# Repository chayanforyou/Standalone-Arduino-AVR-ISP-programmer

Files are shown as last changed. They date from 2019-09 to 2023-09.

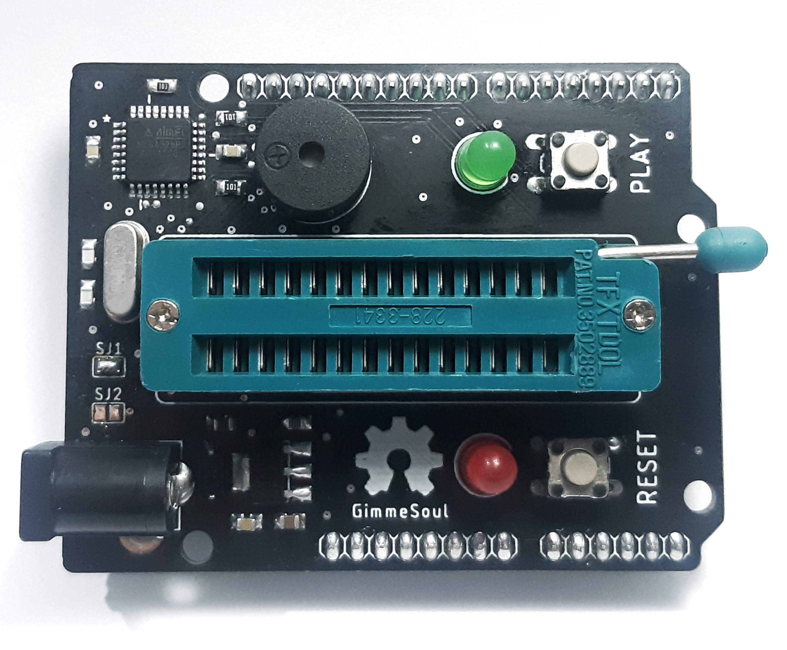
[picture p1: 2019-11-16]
Others/Mounted PCB.jpg

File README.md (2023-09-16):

# Standalone AVR programmer (GimmeSoul)




GimmeSoul is a standalone (no computer needed) bootloader programmer for ATmega328P. It can be used to facilitate programming of chips used by [Arduino UNO](https://store.arduino.cc/usa/arduino-uno-rev3) and [Senaino](https://github.com/import-tiago/Senaino), for example. 

This makes the process of flash the ICs so much faster than conventional way and eliminates the need for a computer.

## Mounted PCB


## PCB Gerber Preview


## Schematic


## Bill of Materials
To mount the components on the board, follow the instructions: [Designator References](https://github.com/import-tiago/GimmeSoul/blob/master/Hardware/1.%20Mounting/Silk%20Screen.png)

| Qty | Parts | Description | Value | Package |
|--|--|--|--|--|
2|R2/R3|SMD Resistor|100R ±5%|R0805
1|R1|SMD Resistor|10k ±5%|R0805
4|C1/C2/C4/C6|SMD Capacitor|100 nF / 50V|C0805
2|C3/C5|SMD Capacitor|1 uF / 50V|C0805
2|C7/C8|SMD Capacitor|22 pF / 50V|C0805
1|D2|SMD Diode|1N4007|SOD123
1|U1|SMD Microcontroller|ATmega328P|TQFP-32
1|U2|SMD Voltage Regulator|LM1117MP-5.0|SOT223
2|S1/S2|PTH Tact Switch|DPST|6 x 6 mm
1|Q1|PTH Crystal|16 MHz|HC49/S
1|SG5|PTH Buzzer|5V Passive|F/QMBIII
1|LED1|PTH LED|Green|5 mm
1|LED2|PTH LED|Red|5 mm
2|JP1/JP4|PTH Pin Header|Male 180°|1X08
1|JP2|PTH Pin Header|Male 180°|1X10
1|JP3|PTH Pin Header|Male 180°|1X06
1|ZX1|PTH ZIF socket|28-pin|Slim Width

## How To
[SETUP Tutorial](https://github.com/import-tiago/GimmeSoul/wiki/SETUP)

## Video
[# GimmeSoul - Demo](https://vimeo.com/363052289?activityReferer=1)

### Contributing
0. Give this project a :star:
1. Create an issue and describe your idea.
2. [Fork it](https://github.com/import-tiago/GimmeSoul/fork).
3. Create your feature branch (`git checkout -b my-new-feature`).
4. Commit your changes (`git commit -a -m "Added feature title"`).
5. Publish the branch (`git push origin my-new-feature`).
6. Create a new pull request.
7. Done! :heavy_check_mark:

### License Information
<br /><span xmlns:dct="http://purl.org/dc/terms/" property="dct:title">GimmeSoul</span> by <a xmlns:cc="http://creativecommons.org/ns#" href="https://github.com/import-tiago" property="cc:attributionName" rel="cc:attributionURL">Tiago Silva</a> is licensed under a <a rel="license" href="http://creativecommons.org/licenses/by-sa/4.0/">Creative Commons Attribution-ShareAlike 4.0 International License</a>.<br />Based on a work at <a xmlns:dct="http://purl.org/dc/terms/" href="[Standalone AVR Chip Programmer](https://learn.adafruit.com/standalone-avr-chip-programmer/)" rel="dct:source">[Standalone AVR Chip Programmer](https://learn.adafruit.com/standalone-avr-chip-programmer/)</a>.<br />Permissions beyond the scope of this license may be available at <a xmlns:cc="http://creativecommons.org/ns#" href="https://twitter.com/import_tiago" rel="cc:morePermissions">tiagodepaulasilva@gmail.com</a>.

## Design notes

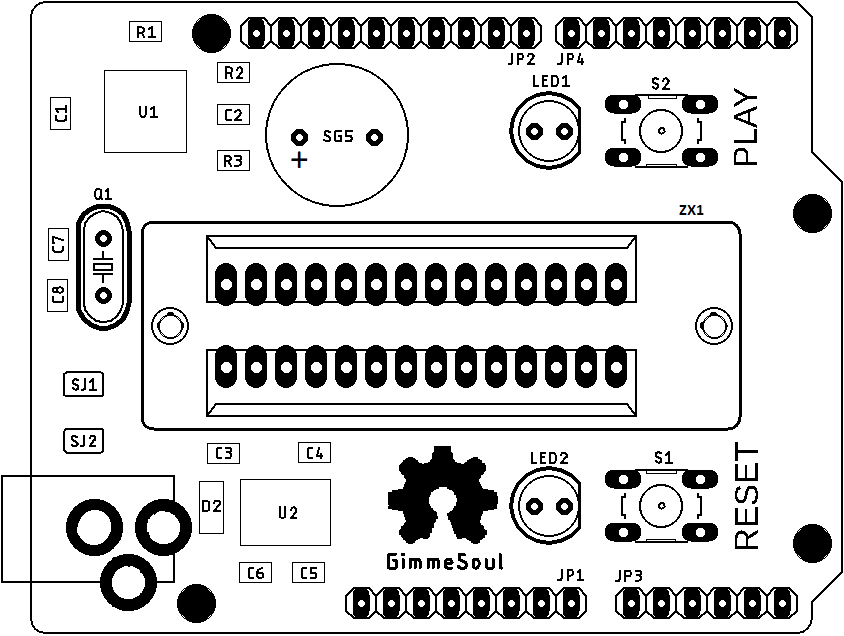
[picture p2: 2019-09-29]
Hardware/1. Mounting/Silk Screen.png

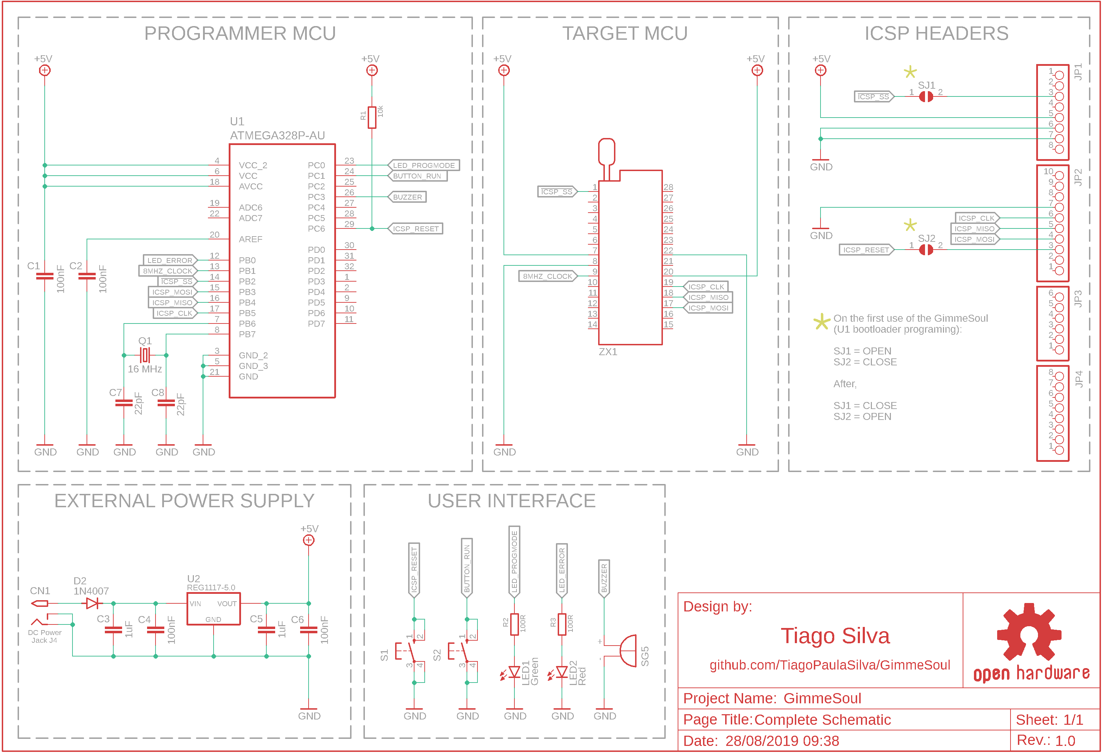
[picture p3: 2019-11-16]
Others/GimmeSoul Schematic Preview.png

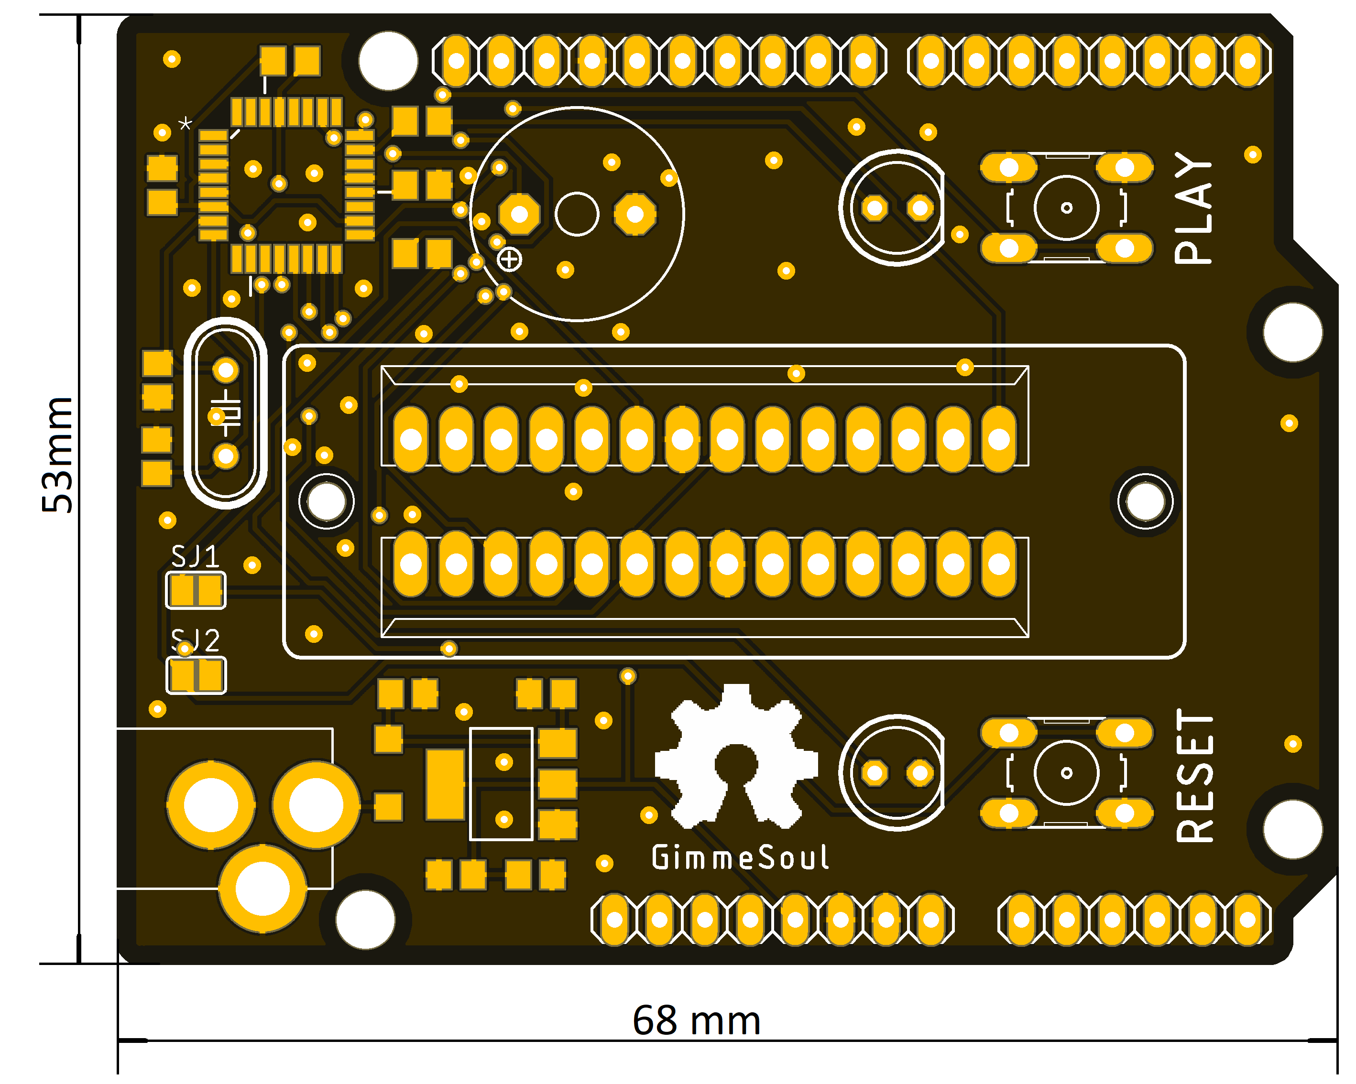
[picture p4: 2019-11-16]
Others/GimmeSoul Gerber Preview.png

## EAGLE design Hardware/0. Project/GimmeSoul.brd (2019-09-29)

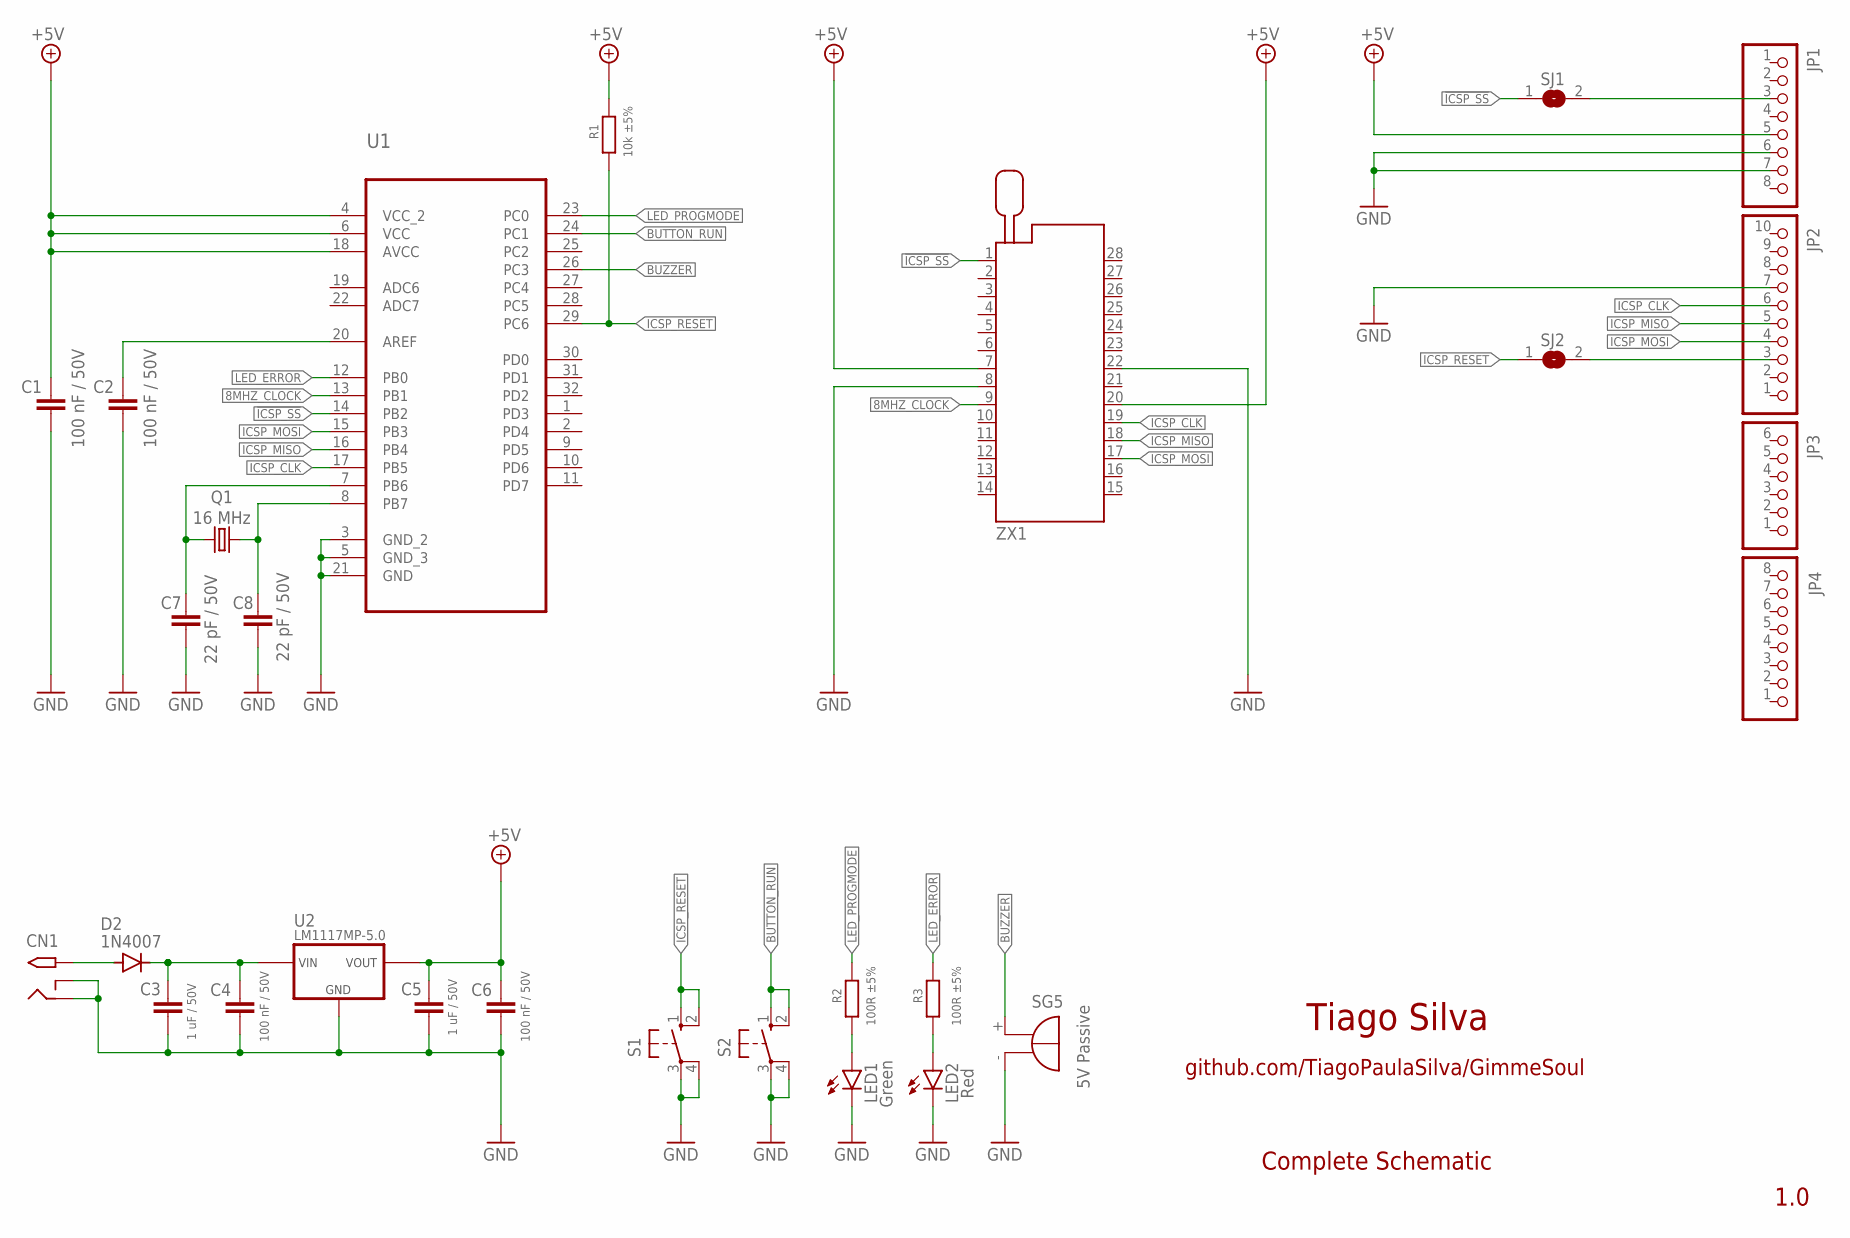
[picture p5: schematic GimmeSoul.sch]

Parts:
C1, C2, C4, C6: 100 nF / 50V; C0805
C3, C5: 1 uF / 50V; C0805
C7, C8: 22 pF / 50V; C0805
CN1: 2.1MMJACKTHM; PJ-102A
D2: 1N4007; SOD123
JP1, JP4: PINHD-1X8; 1X08
JP2: PINHD-1X10_ARD; 1X10
JP3: PINHD-1X6; 1X06
LED1: Green; LED5MM
LED2: Red; LED5MM
Q1: 16 MHz; HC49/S
R1: 10k ±5%; R0805
R2, R3: 100R ±5%; R0805
S1, S2: 10-XX; B3F-10XX
SG5: 5V Passive; F/QMBIII
SJ1, SJ2: SJ
U1: ATMEGA328P-AU; QFP80P900X900X120-32N
U2: LM1117MP-5.0; SOT223
ZX1: 228-4817-00-0602J

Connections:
8MHZ_CLOCK: U1.13 (PB1), ZX1.9
!ICSP_SS: SJ1.1, U1.14 (PB2), ZX1.1
+5V: C1.2, C5.1, C6.1, JP1.5, R1.1, U1.4 (VCC_2), U1.6 (VCC), U1.18 (AVCC), U2.2 (VOUT), U2.4 (VOUT), ZX1.7, ZX1.20
BUTTON_RUN: S2.1 (S), S2.2 (S1), U1.24 (PC1)
BUZZER: SG5.+ (-), U1.26 (PC3)
GND: C1.1, C2.1, C3.2, C4.2, C5.2, C6.2, C7.1, C8.1, CN1.RING, CN1.RING_SW, JP1.6, JP1.7, JP2.7, LED1.K (C), LED2.K (C), S1.3, S1.4 (P1), S2.3, S2.4 (P1), SG5.- (+), U1.3 (GND_2), U1.5 (GND_3), U1.21 (GND), U2.1 (GND), ZX1.8, ZX1.22
ICSP_CLK: JP2.6, U1.17 (PB5), ZX1.19
ICSP_MISO: JP2.5, U1.16 (PB4), ZX1.18
ICSP_MOSI: JP2.4, U1.15 (PB3), ZX1.17
ICSP_RESET: R1.2, S1.1 (S), S1.2 (S1), SJ2.1, U1.29 (PC6)
LED_ERROR: R3.1, U1.12 (PB0)
LED_PROGMODE: R2.1, U1.23 (PC0)
unnamed: LED1.A, R2.2
unnamed: CN1.TIP, D2.A
unnamed: LED2.A, R3.2
unnamed: C3.1, C4.1, D2.C, U2.3 (VIN)
unnamed: JP2.3, SJ2.2
unnamed: JP1.3, SJ1.2
unnamed: C7.2, Q1.1, U1.7 (PB6)
unnamed: C8.2, Q1.2, U1.8 (PB7)
unnamed: C2.2, U1.20 (AREF)

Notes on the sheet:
Tiago Silva
github.com/TiagoPaulaSilva/GimmeSoul
1.0
Complete Schematic

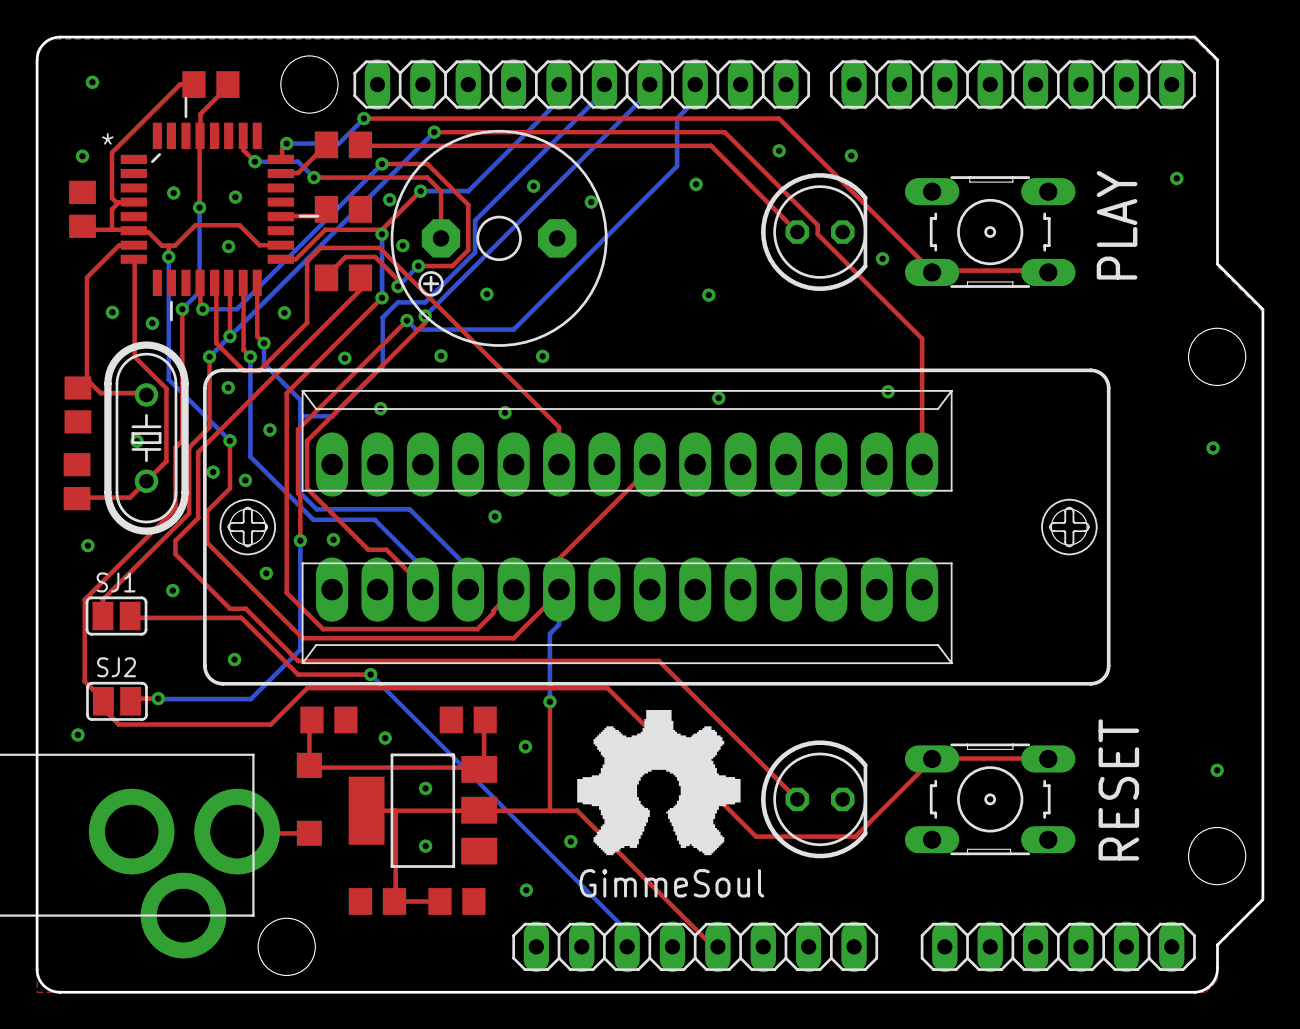
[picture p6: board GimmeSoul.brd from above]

Board: 2 copper layers, 68.6 x 53.5 mm, 28 parts (0 on the bottom side), 21 nets.

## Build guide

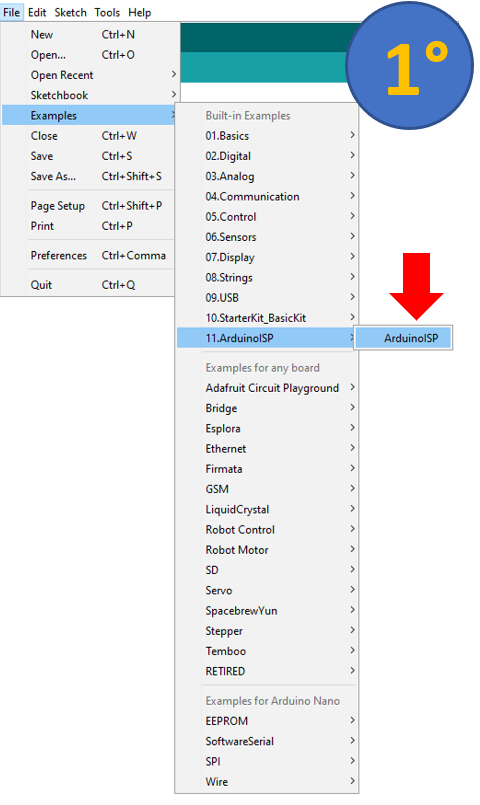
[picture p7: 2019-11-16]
Others/Tutorial/Step (2).png

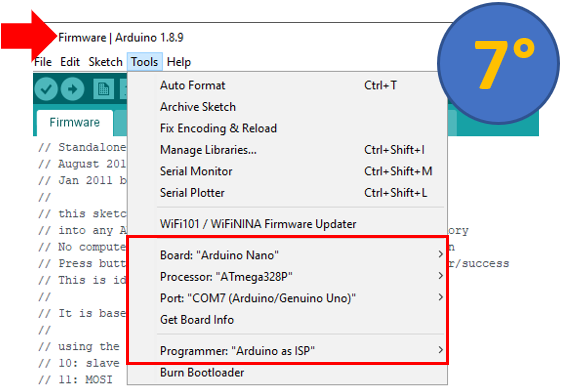
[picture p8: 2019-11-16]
Others/Tutorial/Step (10).png

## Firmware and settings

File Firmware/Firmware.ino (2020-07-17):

// Standalone AVR ISP programmer
// August 2011 by Limor Fried / Ladyada / Adafruit
// Jan 2011 by Bill Westfield ("WestfW")
//
// this sketch allows an Arduino to program a flash program
// into any AVR if you can fit the HEX file into program memory
// No computer is necessary. Two LEDs for status notification
// Press button to program a new chip. Piezo beeper for error/success 
// This is ideal for very fast mass-programming of chips!
//
// It is based on AVRISP
//
// using the following pins:
// 10: slave reset
// 11: MOSI
// 12: MISO
// 13: SCK
//  9: 8 MHz clock output - connect this to the XTAL1 pin of the AVR
//     if you want to program a chip that requires a crystal without
//     soldering a crystal in
// ----------------------------------------------------------------------


#include "optiLoader.h"
#include "SPI.h"

// Global Variables
int pmode=0;
byte pageBuffer[128];		       /* One page of flash */


/*
 * Pins to target
 */
#define SCK 13
#define MISO 12
#define MOSI 11
#define RESET 10
#define CLOCK 9     // self-generate 8mhz clock - handy!

#define BUTTON A1
#define PIEZOPIN A3

// Set to 1 to enable autostart. This automatically starts programming
// when a chip is inserted. How this detection happens is determined by
// the DETECT_* constants below. This is disabled by default, since the
// default settings require adding a pulldown (see below).
#define AUTOSTART 0

// Pin to use for detecting chip presence. This defaults to the
// (target) RESET pin, which detects the (internal) reset pullup on the
// target chip or board. For this to work, there should be a pulldown on
// the programmer side (which is big enough to not interfere with the
// target pullup). Alternatively, for self-powered boards, this could be
// set to an I/O pin that is connected to the targets VCC (still
// requires a pulldown on the programmer side).
#define DETECT RESET

// The DETECT pin level that indicates a chip is present.
#define DETECT_ACTIVE HIGH

// Debounce delay: The DETECT pin must be stable for this long before it
// is seen as changed. This applies both after removing and after
// re-inserting the chip.
#define DETECT_DEBOUNCE_MS 500

void setup () {
  Serial.begin(57600);			/* Initialize serial for status msgs */
  Serial.println("\nAdaBootLoader Bootstrap programmer (originally OptiLoader Bill Westfield (WestfW))");

  pinMode(PIEZOPIN, OUTPUT);

  pinMode(LED_PROGMODE, OUTPUT);
  pulse(LED_PROGMODE,2);
  pinMode(LED_ERR, OUTPUT);
  pulse(LED_ERR, 2);

  pinMode(BUTTON, INPUT);     // button for next programming
  digitalWrite(BUTTON, HIGH); // pullup
  
  pinMode(CLOCK, OUTPUT);
  // setup high freq PWM on pin 9 (timer 1)
  // 50% duty cycle -> 8 MHz
  OCR1A = 0;
  ICR1 = 1;
  // OC1A output, fast PWM
  TCCR1A = _BV(WGM11) | _BV(COM1A1);
  TCCR1B = _BV(WGM13) | _BV(WGM12) | _BV(CS10); // no clock prescale



  
}

#if AUTOSTART != 0
bool detect_chip() {
  // The most recently read detection state (true is chip present, false is no
  // chip present). Default is to assume a chip is present, to prevent
  // autostarting on powerup, only after *inserting* a chip.
  static bool detected = true;
  // The most recent detection state that has been stable.
  static bool debounced = detected;
  // The timestamp of the most recent change, or 0 when the pin is
  // stable.
  static unsigned long last_change = 0;

  // See if the pin changed
  unsigned long now = millis();
  bool prev_detected = detected;
  detected = (digitalRead(DETECT) == DETECT_ACTIVE);

  if (detected != prev_detected)
    last_change = now;

  if (detected != debounced && (now - last_change) > DETECT_DEBOUNCE_MS) {
    // If stable for long enough, update the debounced state and clear
    // the last_change value. Keep the previous value, to detect changes
    last_change = 0;
    debounced = detected;

    // Detect when a chip is inserted
    if (debounced)
      return true;
  }

  // No change, or chip removed
  return false;
}
#endif

void loop (void) {
  #if AUTOSTART != 0
  Serial.println("\nInsert next chip to autostart or type 'G' or hit BUTTON to force start");
  #else
  Serial.println("\nType 'G' or hit BUTTON for next chip");
  #endif
  while (1) {
    #if AUTOSTART != 0
    if (detect_chip()) {
      Serial.println("Chip detected, autostarting..");
      break;
    }
    #endif
    if  ((! digitalRead(BUTTON)) || (Serial.read() == 'G'))
      break;  
  }
    
  target_poweron();			/* Turn on target power */

  uint16_t signature;
  image_t *targetimage;
        
  if (! (signature = readSignature()))		// Figure out what kind of CPU
    error("Signature fail");
  if (! (targetimage = findImage(signature)))	// look for an image
    error("Image fail");

  Serial.println();
  Serial.println("Erasing chip");
  eraseChip();
  
  if (! programFuses(targetimage->image_progfuses))	// get fuses ready to program
    error("Programming Fuses fail");
  
  if (! verifyFuses(targetimage->image_progfuses, targetimage->fusemask) ) {
    error("Failed to verify fuses");
  } 

  Serial.println("Fuses set & verified");
  end_pmode();
  start_pmode();

  byte *hextext = targetimage->image_hexcode;  
  uint16_t pageaddr = 0;
  uint8_t pagesize = pgm_read_byte(&targetimage->image_pagesize);
  Serial.print("Page size: "); Serial.println(pagesize, DEC);
  uint16_t chipsize = pgm_read_word(&targetimage->chipsize);
  Serial.print("Chip size: "); Serial.println(chipsize, DEC);
  
  while (pageaddr < chipsize && hextext) {
     Serial.print("Writing address $"); Serial.println(pageaddr, HEX);
     byte *hextextpos = readImagePage (hextext, pageaddr, pagesize, pageBuffer);
          
     boolean blankpage = true;
     for (uint8_t i=0; i<pagesize; i++) {
       if (pageBuffer[i] != 0xFF) blankpage = false;
     }          
     if (! blankpage) {
       if (! flashPage(pageBuffer, pageaddr, pagesize))	
	       error("Flash programming failed");
     }
     hextext = hextextpos;
     pageaddr += pagesize;
  }
  
  // Set fuses to 'final' state
  if (! programFuses(targetimage->image_normfuses))
    error("Programming Fuses fail");

  delay(100);
  end_pmode();
  delay(100);
  start_pmode();
  delay(100);
  
  Serial.println("\nVerifing flash...");
  if (! verifyImage(targetimage->image_hexcode) ) {
    error("Failed to verify chip");
  } else {
    Serial.println("\tFlash verified correctly!");
  }

  if (! verifyFuses(targetimage->image_normfuses, targetimage->fusemask) ) {
    error("Failed to verify fuses");
  } else {
    Serial.println("Fuses verified correctly!");
  }
  target_poweroff();			/* turn power off */
  programmingSucess();
}

void programmingSucess(){
  tone(PIEZOPIN, 523, 100);
  delay(400);
  tone(PIEZOPIN, 523, 200);
  delay(200);
  tone(PIEZOPIN, 698, 800);
  delay(500);
  digitalWrite(LED_PROGMODE, LOW);
}

void programmingError(){
    digitalWrite(LED_ERR, HIGH);
    digitalWrite(LED_PROGMODE, LOW);
    tone(PIEZOPIN, 622, 500);
    delay(500);
    digitalWrite(LED_ERR, LOW);
    digitalWrite(LED_PROGMODE, HIGH);
    tone(PIEZOPIN, 460, 500);
    delay(500);
}

void error(const char *string) {
  Serial.println(string); 
  digitalWrite(LED_ERR, HIGH);  

  
  while(digitalRead(BUTTON)) {
    programmingError();
  }
  
}

void start_pmode () {
  pinMode(13, INPUT); // restore to default

  SPI.begin();
  SPI.setClockDivider(SPI_CLOCK_DIV128); 
  
  debug("...spi_init done");
  // following delays may not work on all targets...
  pinMode(RESET, OUTPUT);
  digitalWrite(RESET, HIGH);
  pinMode(SCK, OUTPUT);
  digitalWrite(SCK, LOW);
  delay(50);
  digitalWrite(RESET, LOW);
  delay(50);
  pinMode(MISO, INPUT);
  pinMode(MOSI, OUTPUT);
  debug("...spi_transaction");
  spi_transaction(0xAC, 0x53, 0x00, 0x00);
  debug("...Done");
  pmode = 1;
}

void end_pmode () {
  SPI.end();
  digitalWrite(MISO, LOW);		/* Make sure pullups are off too */
  pinMode(MISO, INPUT);
  digitalWrite(MOSI, LOW);
  pinMode(MOSI, INPUT);
  digitalWrite(SCK, LOW);
  pinMode(SCK, INPUT);
  digitalWrite(RESET, LOW);
  pinMode(RESET, INPUT);
  pmode = 0;
}


/*
 * target_poweron
 * begin programming
 */
boolean target_poweron (){
  pinMode(LED_PROGMODE, OUTPUT);
  digitalWrite(LED_PROGMODE, HIGH);
  digitalWrite(RESET, LOW);  // reset it right away.
  pinMode(RESET, OUTPUT);
  delay(100);
  Serial.print("Starting Program Mode");
  start_pmode();
  Serial.println(" [OK]");
  return true;
}

boolean target_poweroff (){
  end_pmode();
  
  return true;
}

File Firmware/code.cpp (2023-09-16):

#include "optiLoader.h"

/*
 * Bootload images.
 * These are the intel Hex files produced by the optiboot makefile,
 * with a small amount of automatic editing to turn them into C strings,
 * and a header attched to identify them
 */

extern image_t *images[];
extern uint8_t NUMIMAGES;

SPISettings fuses_spisettings = SPISettings(100000, MSBFIRST, SPI_MODE0);
SPISettings flash_spisettings = SPISettings(1000000, MSBFIRST, SPI_MODE0);

/*
 * readSignature
 * read the bottom two signature bytes (if possible) and return them
 * Note that the highest signature byte is the same over all AVRs so we skip it
 */

uint16_t readSignature (void)
{
    
  uint16_t target_type = 0;
  Serial.print("\nReading signature:");
  
  SPI.beginTransaction(fuses_spisettings); 
  
  target_type = spi_transaction(0x30, 0x00, 0x01, 0x00);
  target_type <<= 8;
  target_type |= spi_transaction(0x30, 0x00, 0x02, 0x00);

  SPI.endTransaction();
  
  Serial.println(target_type, HEX);
  if (target_type == 0 || target_type == 0xFFFF) {
    if (target_type == 0) {
      Serial.println("  (no target attached?)");
    }
  }
  return target_type;
}

/*
 * findImage
 *
 * given 'signature' loaded with the relevant part of the device signature,
 * search the hex images that we have programmed in flash, looking for one
 * that matches.
 */
image_t *findImage (uint16_t signature)
{
  image_t *ip;
  Serial.println("Searching for image...");

  for (byte i=0; i < NUMIMAGES; i++) {
    ip = images[i];

    if (ip && (pgm_read_word(&ip->image_chipsig) == signature)) {
	Serial.print("  Found \"");
	flashprint(&ip->image_name[0]);
	Serial.print("\" for ");
	flashprint(&ip->image_chipname[0]);
	Serial.println();

	return ip;
    }
  }
  Serial.println(" Not Found");
  return 0;
}

/*
 * programmingFuses
 * Program the fuse/lock bits
 */
boolean programFuses (const byte *fuses)
{
    
  byte f;
  Serial.print("\nSetting fuses");

  busyWait();
  f = pgm_read_byte(&fuses[FUSE_PROT]);
  if (f) {
    Serial.print("\n  Set Lock Fuse to: ");
    Serial.print(f, HEX);
    Serial.print(" -> ");
    SPI.beginTransaction(fuses_spisettings);
    Serial.print(spi_transaction(0xAC, 0xE0, 0x00, f), HEX);
    SPI.endTransaction();
  }
  busyWait();
  f = pgm_read_byte(&fuses[FUSE_LOW]);
  if (f) {
    Serial.print("  Set Low Fuse to: ");
    Serial.print(f, HEX);
    Serial.print(" -> ");
    SPI.beginTransaction(fuses_spisettings);
    Serial.print(spi_transaction(0xAC, 0xA0, 0x00, f), HEX);
    SPI.endTransaction();
  }
  busyWait();
  f = pgm_read_byte(&fuses[FUSE_HIGH]);
  if (f) {
    Serial.print("  Set High Fuse to: ");
    Serial.print(f, HEX);
    Serial.print(" -> ");
    SPI.beginTransaction(fuses_spisettings);
    Serial.print(spi_transaction(0xAC, 0xA8, 0x00, f), HEX);
    SPI.endTransaction();
  }
  busyWait();
  f = pgm_read_byte(&fuses[FUSE_EXT]);
  if (f) {
    Serial.print("  Set Ext Fuse to: ");
    Serial.print(f, HEX);
    Serial.print(" -> ");
    SPI.beginTransaction(fuses_spisettings);
    Serial.print(spi_transaction(0xAC, 0xA4, 0x00, f), HEX);
    SPI.endTransaction();
  }
  Serial.println();
    
  return true;			/* */
}

/*
 * verifyFuses
 * Verifies a fuse set
 */
boolean verifyFuses (const byte *fuses, const byte *fusemask)
{
  byte f;

  Serial.println("Verifying fuses...");
  f = pgm_read_byte(&fuses[FUSE_PROT]);
  if (f) {
    SPI.beginTransaction(fuses_spisettings);
    uint8_t readfuse = spi_transaction(0x58, 0x00, 0x00, 0x00);  // lock fuse
    SPI.endTransaction();

    readfuse &= pgm_read_byte(&fusemask[FUSE_PROT]);
    Serial.print("\tLock Fuse: "); Serial.print(f, HEX);  Serial.print(" is "); Serial.print(readfuse, HEX);
    if (readfuse != f) 
      return false;
  }
  f = pgm_read_byte(&fuses[FUSE_LOW]);
  if (f) {
    SPI.beginTransaction(fuses_spisettings);
    uint8_t readfuse = spi_transaction(0x50, 0x00, 0x00, 0x00);  // low fuse
    SPI.endTransaction();
        
    Serial.print("\tLow Fuse: 0x");  Serial.print(f, HEX); Serial.print(" is 0x"); Serial.print(readfuse, HEX);
    readfuse &= pgm_read_byte(&fusemask[FUSE_LOW]);
    if (readfuse != f) 
      return false;
  }
  f = pgm_read_byte(&fuses[FUSE_HIGH]);
  if (f) {
    SPI.beginTransaction(fuses_spisettings);
    uint8_t readfuse = spi_transaction(0x58, 0x08, 0x00, 0x00);  // high fuse
    SPI.endTransaction();
        
    readfuse &= pgm_read_byte(&fusemask[FUSE_HIGH]);
    Serial.print("\tHigh Fuse: 0x");  Serial.print(f, HEX); Serial.print(" is 0x");  Serial.print(readfuse, HEX);
    if (readfuse != f) 
      return false;
  }
  f = pgm_read_byte(&fuses[FUSE_EXT]);
  if (f) {
    SPI.beginTransaction(fuses_spisettings);
    uint8_t readfuse = spi_transaction(0x50, 0x08, 0x00, 0x00);  // ext fuse
    SPI.endTransaction();
    
    readfuse &= pgm_read_byte(&fusemask[FUSE_EXT]);
    Serial.print("\tExt Fuse: 0x"); Serial.print(f, HEX); Serial.print(" is 0x"); Serial.print(readfuse, HEX);
    if (readfuse != f) 
      return false;
  }
  Serial.println();
  return true;			/* */
}



/*
 * readImagePage
 *
 * Read a page of intel hex image from a string in pgm memory.
*/

// Returns number of bytes decoded
byte * readImagePage (byte *hextext, uint16_t pageaddr, uint8_t pagesize, byte *page)
{
  
  uint16_t len;
  uint8_t page_idx = 0;
  byte *beginning = hextext;
  
  byte b, cksum = 0;

  //Serial.print("page size = "); Serial.println(pagesize, DEC);

  // 'empty' the page by filling it with 0xFF's
  for (uint8_t i=0; i<pagesize; i++)
    page[i] = 0xFF;

  while (1) {
    uint16_t lineaddr;

    // Strip leading whitespace
    byte c;
    do {
      c = pgm_read_byte(hextext++);
    } while (c == ' ' || c == '\n' || c == '\t');

      // read one line!
    if (c != ':') {
      error("No colon?");
      break;
    }
    // Read the byte count into 'len'
    len = hexton(pgm_read_byte(hextext++));
    len = (len<<4) + hexton(pgm_read_byte(hextext++));
    cksum = len;
    
    // read high address byte
    b = hexton(pgm_read_byte(hextext++));  
    b = (b<<4) + hexton(pgm_read_byte(hextext++));
    cksum += b;
    lineaddr = b;
    
    // read low address byte
    b = hexton(pgm_read_byte(hextext++)); 
    b = (b<<4) + hexton(pgm_read_byte(hextext++));
    cksum += b;
    lineaddr = (lineaddr << 8) + b;
    
    if (lineaddr >= (pageaddr + pagesize)) {
      return beginning;
    }

    b = hexton(pgm_read_byte(hextext++)); // record type 
    b = (b<<4) + hexton(pgm_read_byte(hextext++));
    cksum += b;
    //Serial.print("Record type "); Serial.println(b, HEX);
    if (b == 0x1) { 
     // end record, return nullptr to indicate we're done
     hextext = nullptr;
     break;
    }
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

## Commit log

2019-08-27 Schematic designed
    [GimmeSoul.sch]
2019-08-27 Schematic minor improvements
    [GimmeSoul.sch]
2019-08-27 Programing Status Effects Updated
    [GimmeSoul.sch]
2019-08-27 Jumper SJ1 and Button Reset S1 added
    [GimmeSoul.sch]
2019-08-28 External power supply support added
    [GimmeSoul.sch]
2019-08-28 PCB design done
    [GimmeSoul.brd]
2019-08-28 PCB layout minor improvements
    [GimmeSoul.brd]
2019-08-28 Schamatic image exported
    [GimmeSoul.sch]
2019-08-28 Jumpers on PCB layout bug fix
    [GimmeSoul.brd, GimmeSoul.sch]
2019-08-28 Arduino pinouts diagram pdf added
2019-08-28 16MHz crystal added to MCU
    [GimmeSoul.brd, GimmeSoul.sch]
2019-09-29 Silk Screen ref generated
    [GimmeSoul.brd, GimmeSoul.sch]
2023-09-16 Fix bug for no 128 byte page size
    [code.cpp]
